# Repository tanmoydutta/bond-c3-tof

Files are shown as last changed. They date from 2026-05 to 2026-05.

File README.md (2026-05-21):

# bond-c3-tof
A time of flight sensor integrated with ESP32-C3

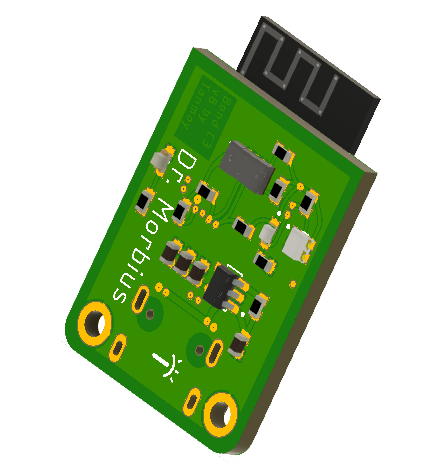
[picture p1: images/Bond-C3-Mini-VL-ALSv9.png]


It also has a matching 3D printed box to house the circuit along with an option to stick a 12x3mm neodymium magnet to stick this to a metallic surface

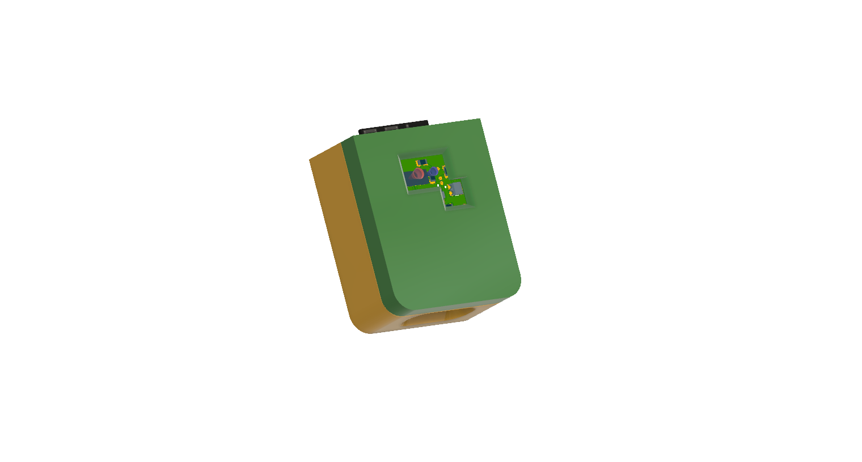
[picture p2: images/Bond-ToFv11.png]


This project is certified as Open Source Hardware - 
<p align="center">
  <a href="https://certification.oshwa.org/nl000041.html">
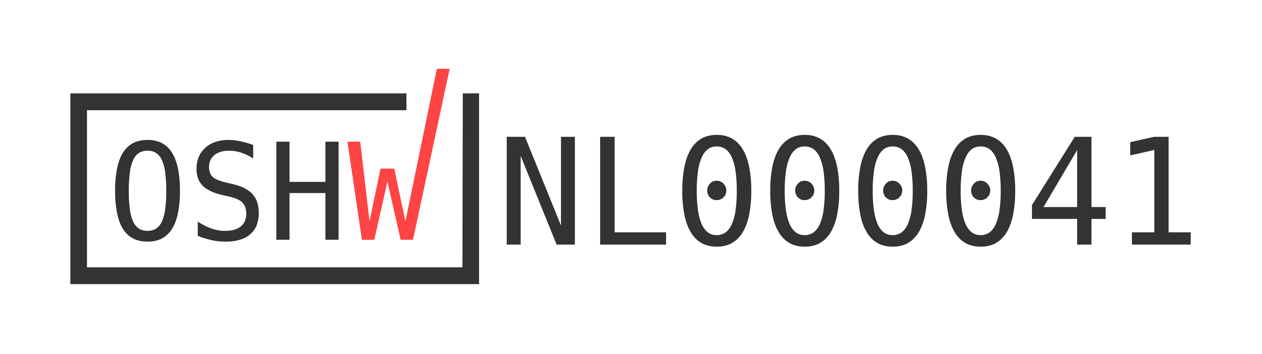
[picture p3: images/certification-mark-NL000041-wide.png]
OSHWA OSHWA Certification
    
  </a>
</p>



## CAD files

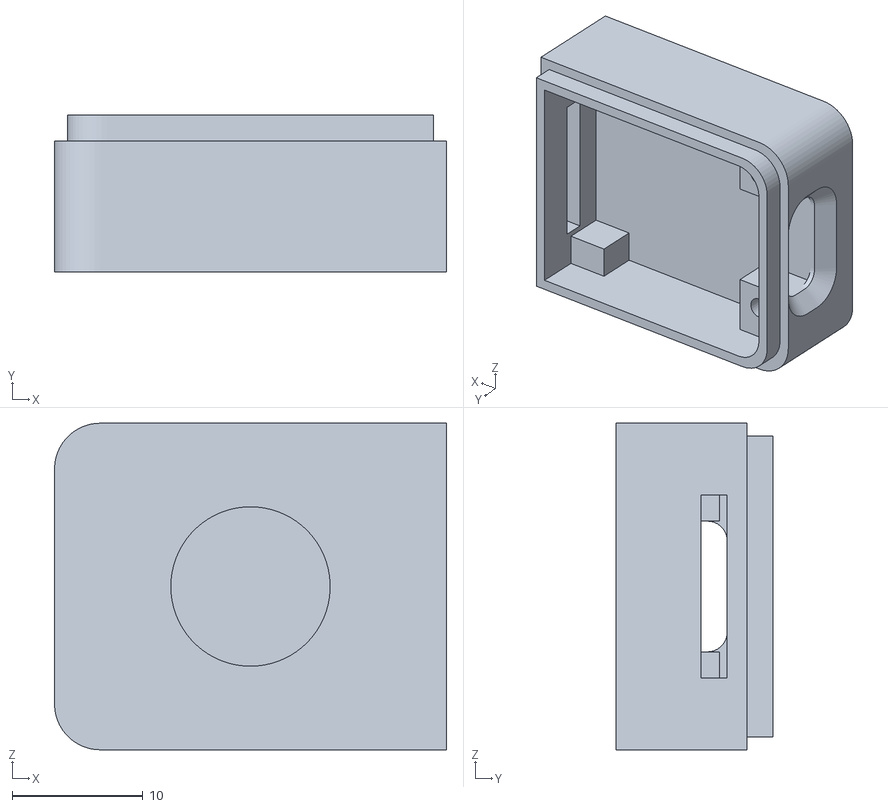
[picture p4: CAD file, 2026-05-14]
3D/Bond-Bot-4.stl
30.0 x 12.0 x 25.0

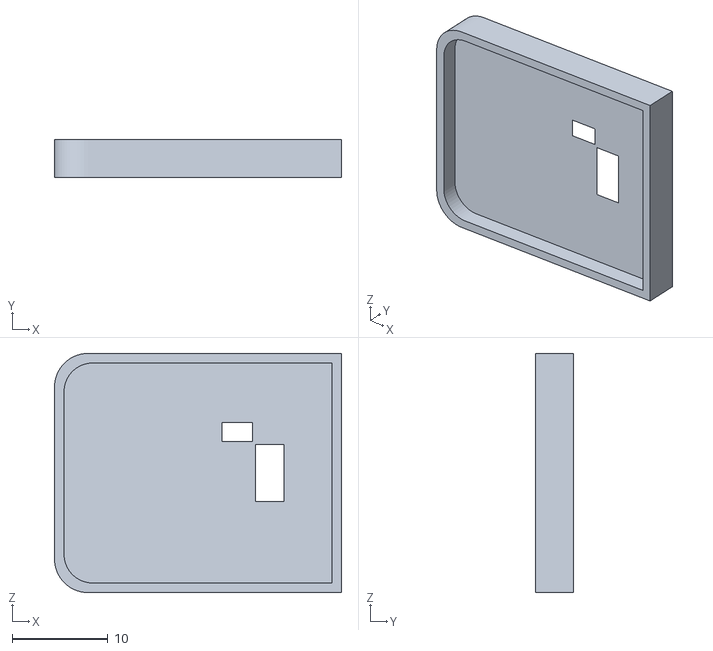
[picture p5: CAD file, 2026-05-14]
3D/Bond-Top-1.stl
30.0 x 4.00 x 25.0

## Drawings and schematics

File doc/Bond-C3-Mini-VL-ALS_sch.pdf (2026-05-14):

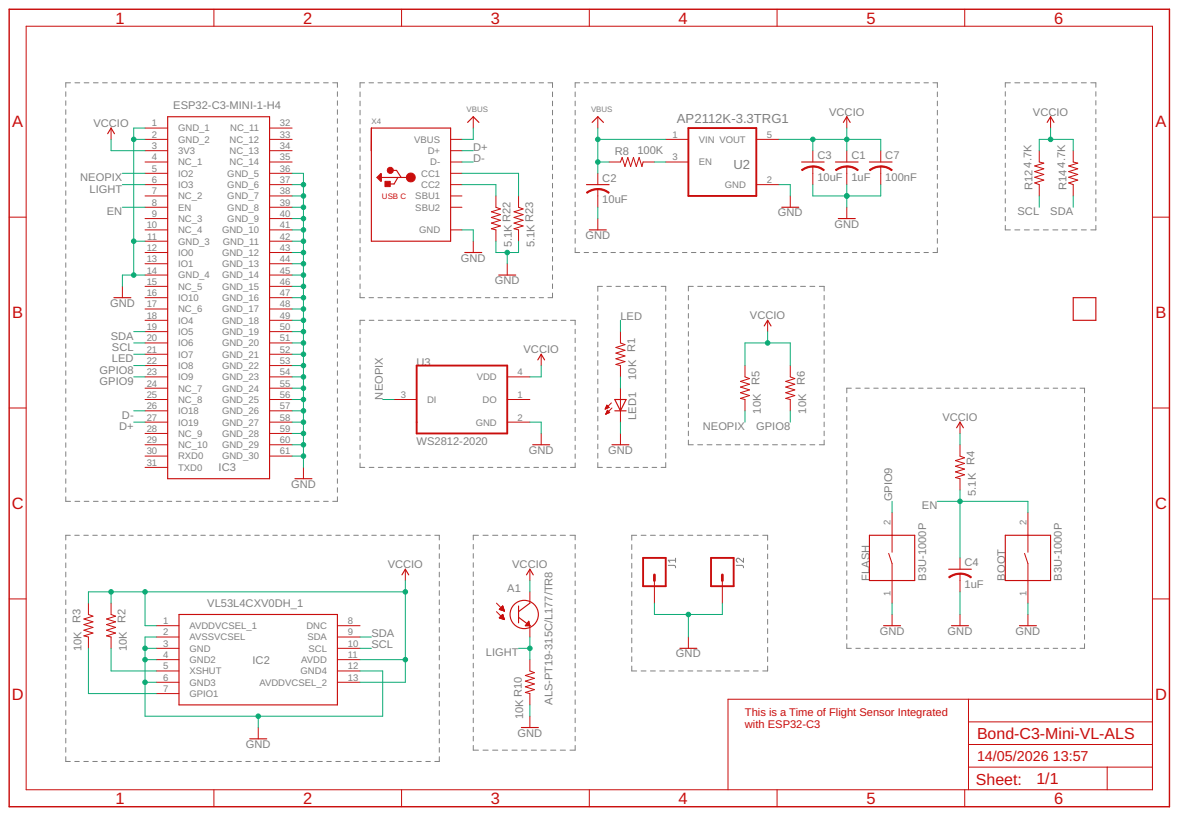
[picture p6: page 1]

This is a Time of Flight Sensor Integrated with ESP32-C3

Bond-C3-Mini-VL-ALS

Sheet: 1/1

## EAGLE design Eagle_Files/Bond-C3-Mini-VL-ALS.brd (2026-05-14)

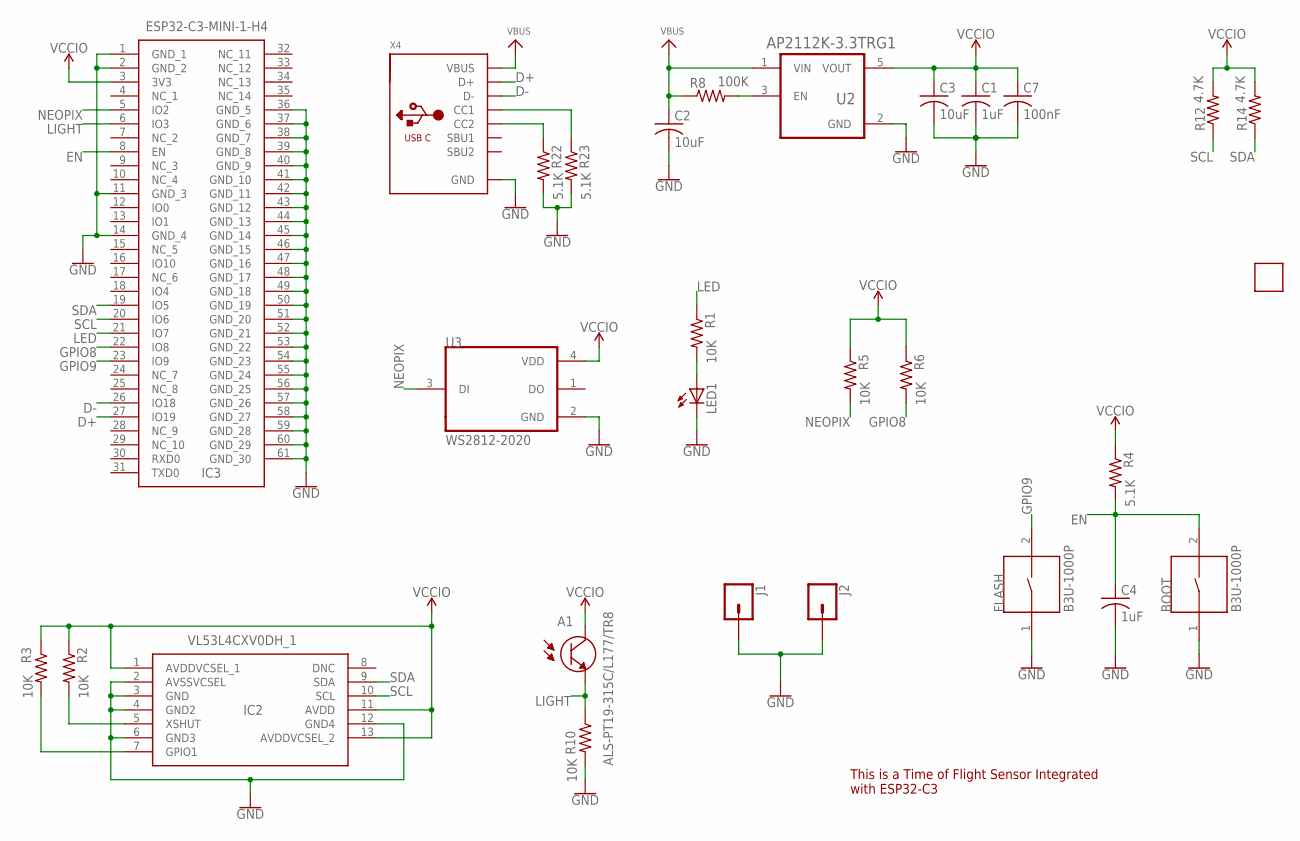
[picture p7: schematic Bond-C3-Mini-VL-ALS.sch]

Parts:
A1: ALS-PT19-315C/L177/TR8; XDCR_ALS-PT19-315C/L177/TR8
BOOT: B3U-1000P; SW_B3U-1000P
C1, C4: 1uF; C0402
C2, C3: 10uF; C0402
C7: 100nF; C0402
FLASH: B3U-1000P; SW_B3U-1000P
IC2: VL53L4CXV0DH_1; VL53L4CXV0DH1
IC3: ESP32-C3-MINI-1-H4; ESP32C3MINI1H4
J1, J2: CONN_01PTH_2MM; 1X01_2MM
LED1: LEDCHIP-LED0603; CHIP-LED0603
R1, R2, R3, R5, R6, R10: 10K; R0402
R4, R22, R23: 5.1K; R0402
R8: 100K; R0402
R12, R14: 4.7K; R0402
U2: AP2112K-3.3TRG1; SOT95P285X140-5N
U3: WS2812-2020; LED_WS2812-2020
U$1: SMARTT_SMALL
X4: MICROBUILDER_USB_C; MICROBUILDER_USB_C_CUSB31-CFM2AX-01-X

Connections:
D+: IC3.27 (IO19), X4.A6 (D+), X4.B6 (D+)
D-: IC3.26 (IO18), X4.A7 (D-), X4.B7 (D-)
EN: BOOT.2, C4.1, IC3.8 (EN), R4.2
GND: BOOT.1, C1.2, C2.2, C3.2, C4.2, C7.2, FLASH.1, IC2.2 (AVSSVCSEL), IC2.3 (GND), IC2.4 (GND2), IC2.6 (GND3), IC2.12 (GND4), IC3.1 (GND_1), IC3.2 (GND_2), IC3.11 (GND_3), IC3.14 (GND_4), IC3.36 (GND_5), IC3.37 (GND_6), IC3.38 (GND_7), IC3.39 (GND_8), IC3.40 (GND_9), IC3.41 (GND_10), IC3.42 (GND_11), IC3.43 (GND_12), IC3.44 (GND_13), IC3.45 (GND_14), IC3.46 (GND_15), IC3.47 (GND_16), IC3.48 (GND_17), IC3.49 (GND_18), IC3.50 (GND_19), IC3.51 (GND_20), IC3.52 (GND_21), IC3.53 (GND_22), IC3.54 (GND_23), IC3.55 (GND_24), IC3.56 (GND_25), IC3.57 (GND_26), IC3.58 (GND_27), IC3.59 (GND_28), IC3.60 (GND_29), IC3.61 (GND_30), J1.1, J2.1, LED1.C, R10.2, R22.2, R23.2, U2.2 (GND), U3.2 (GND), X4.A1B12 (GND), X4.B1A12 (GND)
GPIO8: IC3.22 (IO8), R6.2
GPIO9: FLASH.2, IC3.23 (IO9)
LED: IC3.21 (IO7), R1.1
LIGHT: A1.2 (E), IC3.6 (IO3), R10.1
unnamed: IC2.7 (GPIO1), R3.2
unnamed: IC2.5 (XSHUT), R2.2
unnamed: LED1.A, R1.2
unnamed: R22.1, X4.B5 (CC2)
unnamed: R23.1, X4.A5 (CC1)
unnamed: R8.2, U2.3 (EN)
NEOPIX: IC3.5 (IO2), R5.2, U3.3 (DI)
SCL: IC2.10 (SCL), IC3.20 (IO6), R12.1
SDA: IC2.9 (SDA), IC3.19 (IO5), R14.1
VBUS: C2.1, R8.1, U2.1 (VIN), X4.A4B9 (VBUS), X4.B4A9 (VBUS)
VCCIO: A1.1 (C), C1.1, C3.1, C7.1, IC2.1 (AVDDVCSEL_1), IC2.11 (AVDD), IC2.13 (AVDDVCSEL_2), IC3.3 (3V3), R2.1, R3.1, R4.1, R5.1, R6.1, R12.2, R14.2, U2.5 (VOUT), U3.4 (VDD)

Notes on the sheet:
This is a Time of Flight Sensor Integrated with ESP32-C3

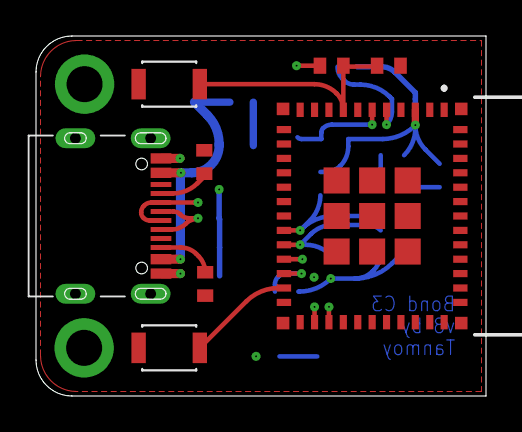
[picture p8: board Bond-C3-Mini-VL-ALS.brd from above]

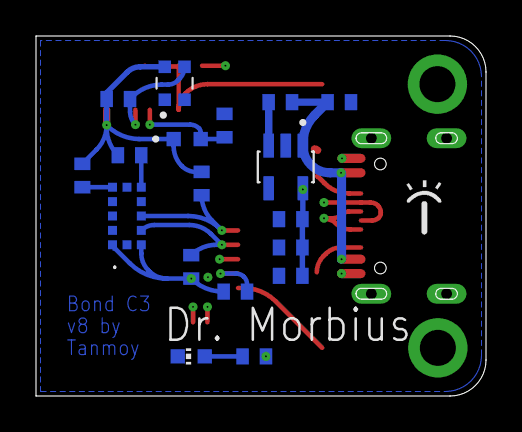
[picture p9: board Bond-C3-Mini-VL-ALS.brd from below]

Board: 4 copper layers, 25.0 x 20.0 mm, 29 parts (18 on the bottom side), 19 nets.

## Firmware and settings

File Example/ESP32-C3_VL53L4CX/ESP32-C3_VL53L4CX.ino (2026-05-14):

/**
 ******************************************************************************
 * @file    VL53L4CX_Sat_HelloWorld.ino
 * @author  SRA
 * @version V1.0.0
 * @date    16 March 2022
 * @brief   Arduino test application for the STMicrolectronics VL53L4CX
 *          proximity sensor satellite based on FlightSense.
 *          This application makes use of C++ classes obtained from the C
 *          components' drivers.
 ******************************************************************************
 * @attention
 *
 * <h2><center>&copy; COPYRIGHT(c) 2022 STMicroelectronics</center></h2>
 *
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
 ******************************************************************************
 */
/*
 * To use this sketch you need to connect the VL53L4CD satellite sensor directly to the Nucleo board with wires in this way:
 * pin 1 (GND) of the VL53L4CD satellite connected to GND of the Nucleo board
 * pin 2 (VDD) of the VL53L4CD satellite connected to 3V3 pin of the Nucleo board
 * pin 3 (SCL) of the VL53L4CD satellite connected to pin D15 (SCL) of the Nucleo board
 * pin 4 (SDA) of the VL53L4CD satellite connected to pin D14 (SDA) of the Nucleo board
 * pin 5 (GPIO1) of the VL53L4CD satellite connected to pin A2 of the Nucleo board
 * pin 6 (XSHUT) of the VL53L4CD satellite connected to pin A1 of the Nucleo board
 */
/* Includes ------------------------------------------------------------------*/
#include <Arduino.h>
#include <Wire.h>
#include <vl53l4cx_class.h>
#include <string.h>
#include <stdlib.h>
#include <stdio.h>
#include <stdint.h>
#include <assert.h>
#include <stdlib.h>

#define DEV_I2C Wire
#define SerialPort Serial

#ifndef LED_BUILTIN
  #define LED_BUILTIN 13
#endif
#define LedPin LED_BUILTIN

// Components.
VL53L4CX sensor_vl53l4cx_sat(&DEV_I2C, A1);

/* Setup ---------------------------------------------------------------------*/

void setup()
{
  // Led.
  //pinMode(LedPin, OUTPUT);

  // Initialize serial for output.
  SerialPort.begin(115200);
  SerialPort.println("Starting...");

  // Initialize I2C bus.
  DEV_I2C.begin();

  // Configure VL53L4CX satellite component.
  sensor_vl53l4cx_sat.begin();

  // Switch off VL53L4CX satellite component.
  sensor_vl53l4cx_sat.VL53L4CX_Off();

  //Initialize VL53L4CX satellite component.
  sensor_vl53l4cx_sat.InitSensor(0x12);

  // Start Measurements
  sensor_vl53l4cx_sat.VL53L4CX_StartMeasurement();
}

void loop()
{
  VL53L4CX_MultiRangingData_t MultiRangingData;
  VL53L4CX_MultiRangingData_t *pMultiRangingData = &MultiRangingData;
  uint8_t NewDataReady = 0;
  int no_of_object_found = 0, j;
  char report[64];
  int status;

  do {
    status = sensor_vl53l4cx_sat.VL53L4CX_GetMeasurementDataReady(&NewDataReady);
  } while (!NewDataReady);

  //Led on
  //digitalWrite(LedPin, HIGH);

  if ((!status) && (NewDataReady != 0)) {
    status = sensor_vl53l4cx_sat.VL53L4CX_GetMultiRangingData(pMultiRangingData);
    no_of_object_found = pMultiRangingData->NumberOfObjectsFound;
    snprintf(report, sizeof(report), "VL53L4CX Satellite: Count=%d, #Objs=%1d ", pMultiRangingData->StreamCount, no_of_object_found);
    SerialPort.print(report);
    for (j = 0; j < no_of_object_found; j++) {
      if (j != 0) {
        SerialPort.print("\r\n                               ");
      }
      SerialPort.print("status=");
      SerialPort.print(pMultiRangingData->RangeData[j].RangeStatus);
      SerialPort.print(", D=");
      SerialPort.print(pMultiRangingData->RangeData[j].RangeMilliMeter);
      SerialPort.print("mm");
      SerialPort.print(", Signal=");
      SerialPort.print((float)pMultiRangingData->RangeData[j].SignalRateRtnMegaCps / 65536.0);
      SerialPort.print(" Mcps, Ambient=");
      SerialPort.print((float)pMultiRangingData->RangeData[j].AmbientRateRtnMegaCps / 65536.0);
      SerialPort.print(" Mcps");
    }
    SerialPort.println("");
    if (status == 0) {
      status = sensor_vl53l4cx_sat.VL53L4CX_ClearInterruptAndStartMeasurement();
    }
  }

  //digitalWrite(LedPin, LOW);
}

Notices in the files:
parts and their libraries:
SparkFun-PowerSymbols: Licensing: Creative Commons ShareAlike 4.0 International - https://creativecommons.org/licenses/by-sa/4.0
